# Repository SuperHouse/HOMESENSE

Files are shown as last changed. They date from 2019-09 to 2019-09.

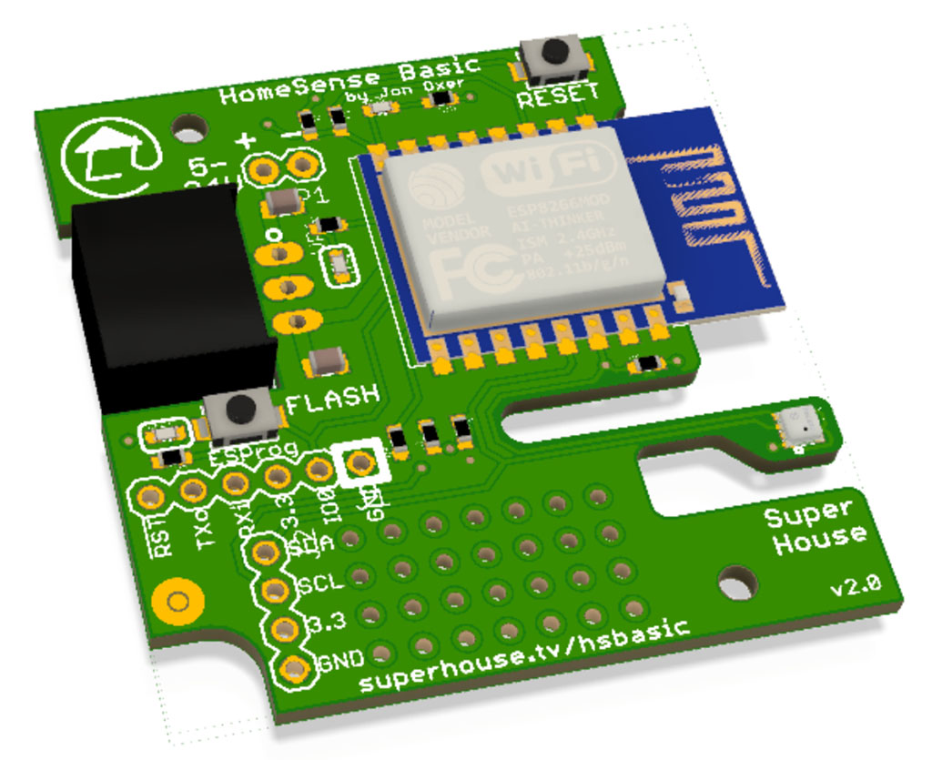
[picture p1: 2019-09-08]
images/HSBASIC-v2_0-render.jpg

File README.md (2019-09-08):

HomeSense Basic Environmental Sensor
====================================
Copyright 2018-2019 SuperHouse Pty Ltd  www.superhouse.tv  

Environmental sensor for home automation systems. Includes:

 * ESP8266 processor with WiFi
 * Switchmode voltage regulator for wide input voltage range
 * BME280 barometric pressure, temperature, and humidity sensor
 * I2C breakout with prototyping area
 * Designed to run Tasmota firmware

More information at

  http://www.superhouse.tv/hsbasic

INSTALLATION
------------
The design is saved as an EAGLE project. EAGLE PCB design software is
available from www.cadsoftusa.com free for non-commercial use. To use
this project download it and place the directory containing these files
into the "eagle" directory on your computer. Then open EAGLE and
navigate to the project.

DISTRIBUTION
------------
The specific terms of distribution of this project are governed by the
license referenced below.

LICENSE
-------
Licensed under the TAPR Open Hardware License (www.tapr.org/OHL).
The "license" folder within this repository also contains a copy of
this license in plain text format.

CREDIT
-------
Designed by Jonathan Oxer

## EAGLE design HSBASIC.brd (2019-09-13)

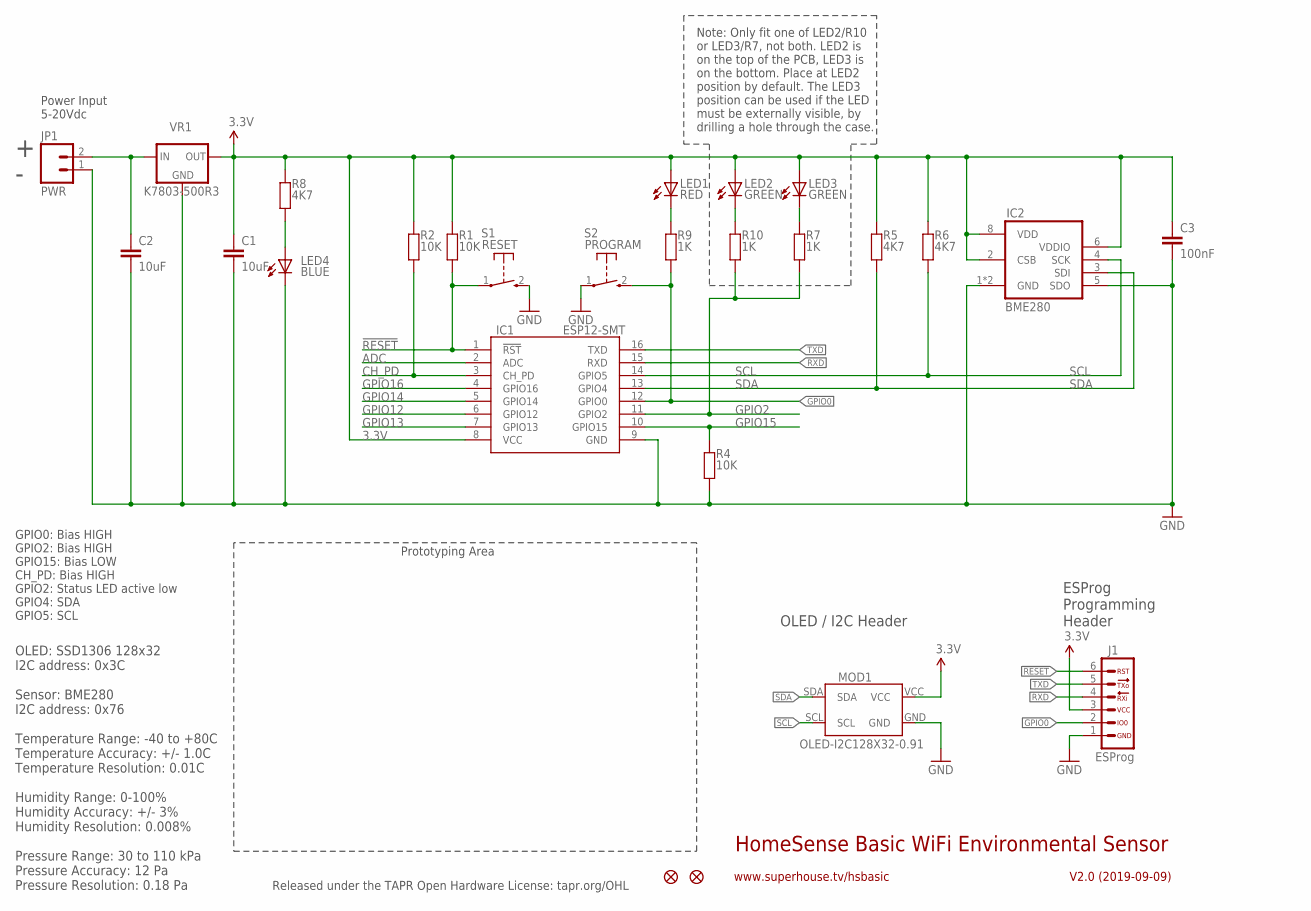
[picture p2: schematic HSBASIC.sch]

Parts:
C1, C2: 10uF; C0805
C3: 100nF; C0603
FID2, FID3: FIDUCIAL1X2.5; FIDUCIAL-1X2.5
IC1: ESP12-SMT; ESP12
IC2: BME280
J1: ESPROG-SOCKET; ESPROG-S
JP1: PWR; 1X02
LED1: RED; LED-0603
LED2, LED3: GREEN; LED-0603
LED4: BLUE; LED-0603
MOD1: OLED-I2C128X32-0.91; OLED-128X32-0.91
R1, R2, R4: 10K; R0603
R5, R6, R8: 4K7; R0603
R7, R9, R10: 1K; R0603
S1: RESET; TACTILE_SMT_3X4X2
S2: PROGRAM; TACTILE_SMT_3X4X2
VR1: K7803-500R3; K78XX-500R3-FLAT

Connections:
3.3V: C1.1, C3.1, IC1.8 (VCC), IC2.2 (CSB), IC2.6 (VDDIO), IC2.8 (VDD), J1.3, LED1.A, LED2.A, LED3.A, MOD1.VCC, R1.2, R2.2, R5.2, R6.2, R8.2, VR1.3 (OUT)
!RESET: IC1.1 (!RST), J1.6, R1.1, S1.1
ADC: IC1.2 (ADC)
CH_PD: IC1.3 (CH_PD), R2.1
GND: C1.2, C2.2, C3.2, IC1.9 (GND), IC2.1 (GND), IC2.5 (SDO), IC2.7 (GND), J1.1, JP1.1, LED4.C, MOD1.GND, R4.1, S1.2 (S), S2.1, VR1.2 (GND)
GPIO0: IC1.12 (GPIO0), J1.2, R9.1, S2.2 (S)
GPIO2: IC1.11 (GPIO2), R7.1, R10.1
GPIO12: IC1.6 (GPIO12)
GPIO13: IC1.7 (GPIO13)
GPIO14: IC1.5 (GPIO14)
GPIO15: IC1.10 (GPIO15), R4.2
GPIO16: IC1.4 (GPIO16)
unnamed: C2.1, JP1.2, VR1.1 (IN)
unnamed: LED4.A, R8.1
unnamed: LED1.C, R9.2
unnamed: LED3.C, R7.2
unnamed: LED2.C, R10.2
RXD: IC1.15 (RXD), J1.4
SCL: IC1.14 (GPIO5), IC2.4 (SCK), MOD1.SCL, R6.1
SDA: IC1.13 (GPIO4), IC2.3 (SDI), MOD1.SDA, R5.1
TXD: IC1.16 (TXD), J1.5

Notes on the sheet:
HomeSense Basic WiFi Environmental Sensor
V2.0 (2019-09-09)
www.superhouse.tv/hsbasic
Released under the TAPR Open Hardware License: tapr.org/OHL
GPIO0: Bias HIGH GPIO2: Bias HIGH GPIO15: Bias LOW CH_PD: Bias HIGH GPIO2: Status LED active low GPIO4: SDA GPIO5: SCL
OLED: SSD1306 128x32 I2C address: 0x3C Sensor: BME280 I2C address: 0x76 Temperature Range: -40 to +80C Temperature Accuracy: +/- 1.0C Temperature Resolution: 0.01C Humidity Range: 0-100% Humidity Accuracy: +/- 3% Humidity Resolution: 0.008% Pressure Range: 30 to 110 kPa Pressure Accuracy: 12 Pa Pre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
Power Input 5-20Vdc
Note: Only fit one of LED2/R10 or LED3/R7, not both. LED2 is on the top of the PCB, LED3 is on the bottom. Place at LED2 position by default. The LED3 position can be used if the LED must be externally visible, by drilling a hole through the case.
ESProg Programming Header
Prototyping Area
OLED / I2C Header

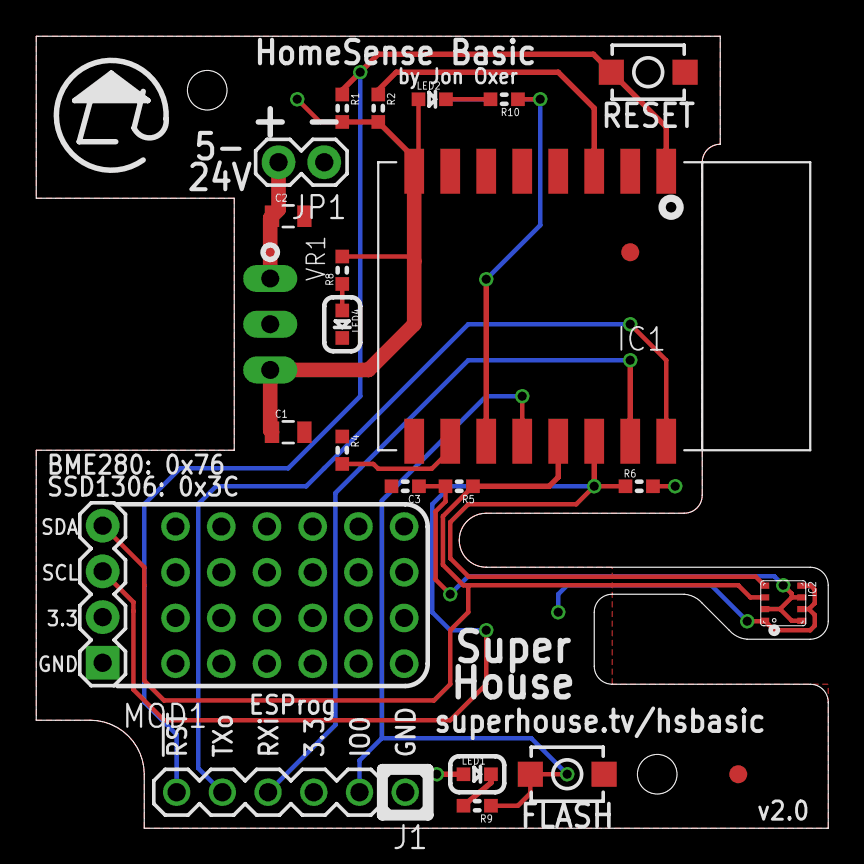
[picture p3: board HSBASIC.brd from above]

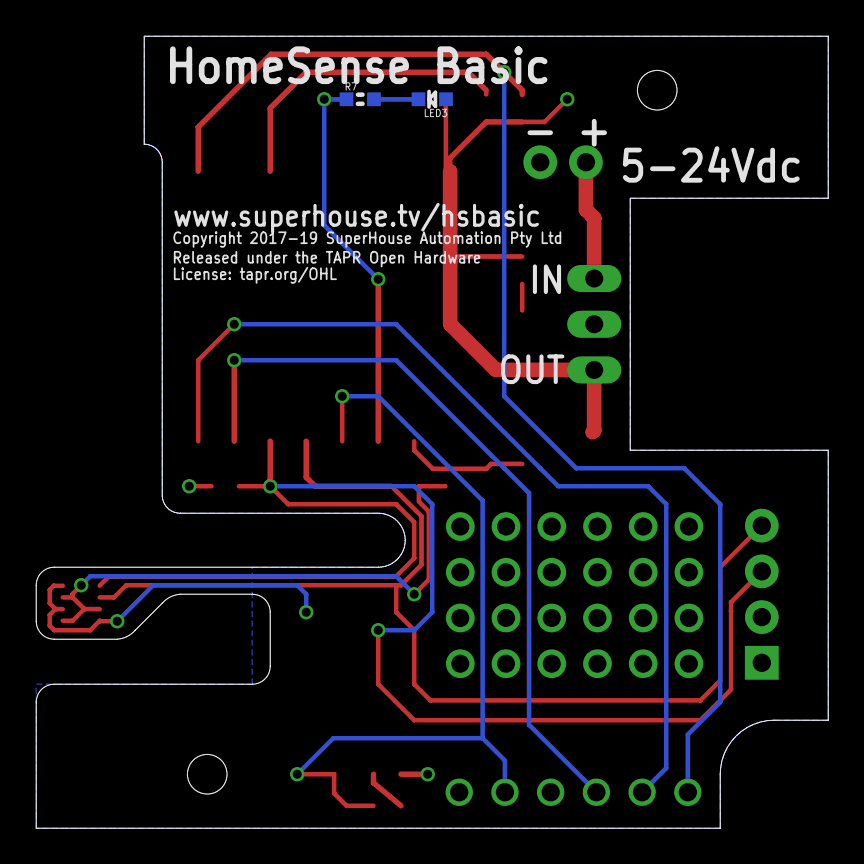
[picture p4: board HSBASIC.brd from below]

Board: 2 copper layers, 44.0 x 44.0 mm, 26 parts (2 on the bottom side), 16 nets.

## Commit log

2018-02-14 Initial project import
    [HomeSenseBasic.brd, HomeSenseBasic.sch]
2018-03-08 Updated routing and schematic for v1.0 release
    [HomeSenseBasic.brd, HomeSenseBasic.sch]
2018-03-28 Fixed ESP12 footprint with correct GPIO4/5
    [HomeSenseBasic.brd, HomeSenseBasic.sch]
2018-03-28 Renamed project files
    [HSBASIC.brd, HSBASIC.sch]
2019-09-03 Switch to BME280 sensor for Tasmota compatibility
    [HSBASIC.brd, HSBASIC.sch]
2019-09-03 Routing progress
    [HSBASIC.brd, HSBASIC.sch]
2019-09-07 Routing I2C
    [HSBASIC.brd, HSBASIC.sch]
2019-09-08 Hopefully final routing for v2.0 release
    [HSBASIC.brd, HSBASIC.sch]
2019-09-09 Major restructure to add OLED and prototyping area
    [HSBASIC.brd, HSBASIC.sch]
2019-09-13 Final tweaks plus ERC and DRC for v2.0 release
    [HSBASIC.brd, HSBASIC.sch]

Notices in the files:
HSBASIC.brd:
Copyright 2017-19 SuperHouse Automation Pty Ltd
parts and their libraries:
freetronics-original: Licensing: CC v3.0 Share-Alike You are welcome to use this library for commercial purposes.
